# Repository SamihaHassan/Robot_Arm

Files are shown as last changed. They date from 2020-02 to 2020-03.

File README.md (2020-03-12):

# Robot_Arm
#### **``Purpose:``**

We aim to create a 2DOF parallel link robot arm that plays piano

#### **``Components:``**
* **Micro-controller:**  Arduino Mega 2560 board
* **Controller:** PID, made by [Samiha](https://github.com/SamihaHassan) and [Gaurika](https://github.com/GaurikaSohnvi)
* **Motor:** custom made reluctant motor by [John](https://github.com/JohnForssander) and Robert

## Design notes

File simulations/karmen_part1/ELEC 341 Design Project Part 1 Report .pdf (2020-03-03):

# Entire System Together

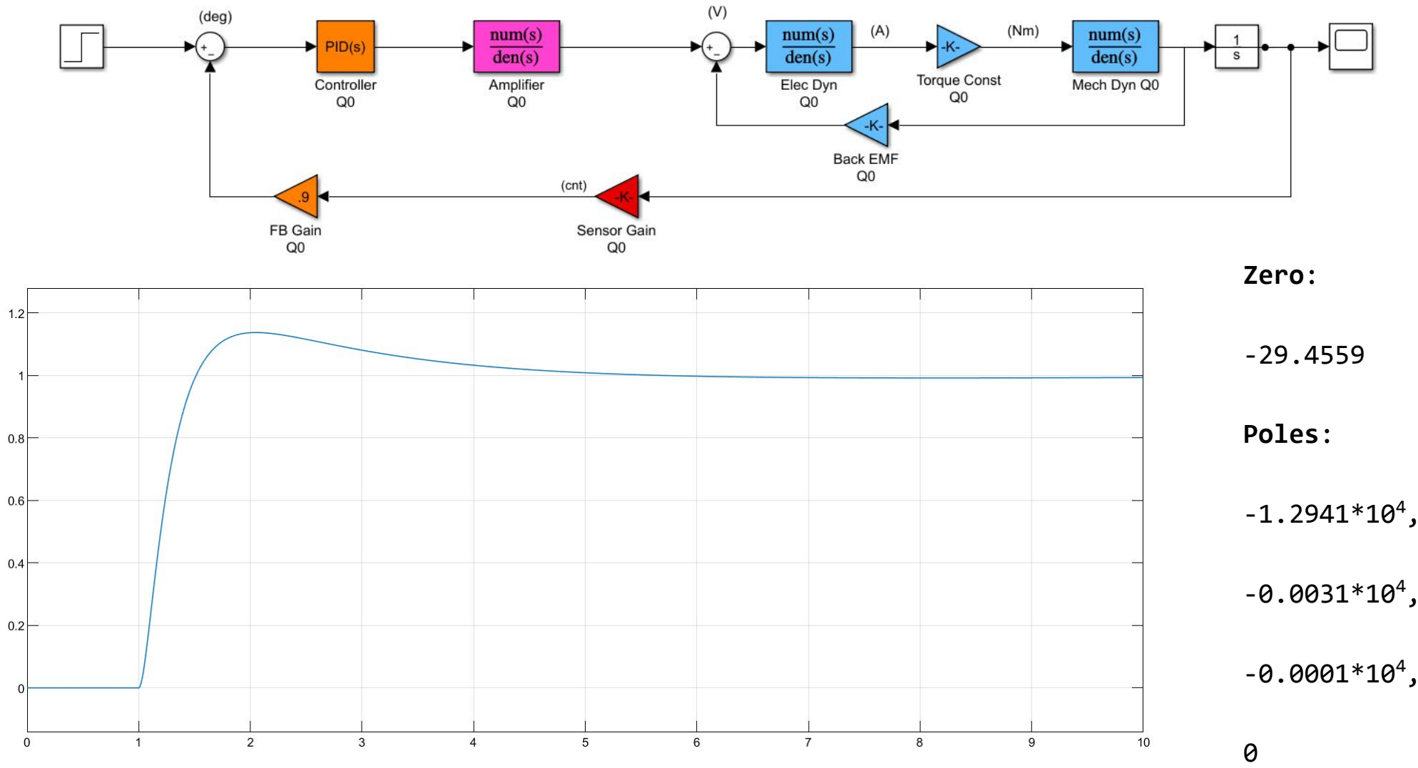
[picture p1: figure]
Zero:; Poles:

,

,

,

0 | 1

This is the overall schematic of our model. As seen, there is a PID(s) that gets multiplied by our linearized open loop response (the blue blocks), which outputs the angle (in radians) the 4 bar robotic arm will perform. To make the output in degrees a ‘radians to degrees’ block would be added after the integrator block. The feedback gain, is responsible for converting the analog signal from the sensor to an angular position measurement, as we are working with a linearized system, the FB gain will be 1/(sensor gain) to obtain unity gain.

We also used the top block diagram to test and generate the below step response that utilizes our PID gains computed (page 7). Using Matlab’s zero() and pole() functions we found the characteristics of the open-loop transfer function (provided above).

This report will detail the methods used to obtain the transfer functions of each component used in the system.

# Power Amplifier Circuit

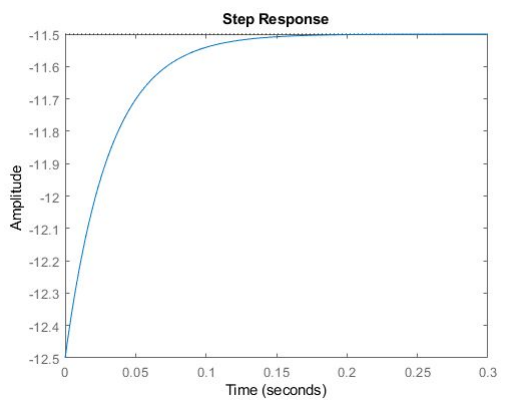
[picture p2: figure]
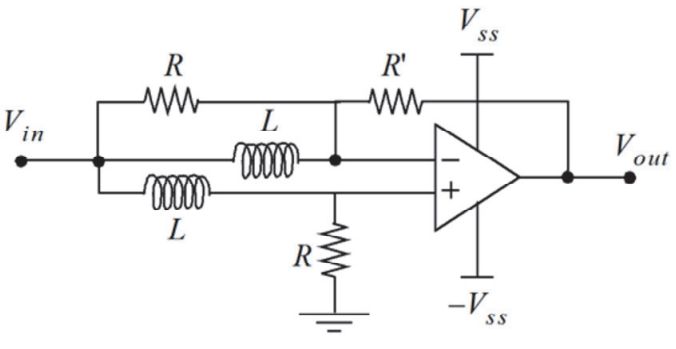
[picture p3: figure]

2

To compute the transfer function of the Power Amplifier circuit, we did the following:
- Transform the circuit into the Laplace domain, replace the components with their equivalent impedances (L becomes Ls for instance)
- Write out the following KCL equations and use MNA
- Also need to recognize that the amplifier has negative feedback therefore we can use the notion that V+ = V-
- Also recognize that there is no current being delivered to the non-inverting and inverting inputs to the OpAmp
Once this was done, we were able to determine the transfer function equation and simply replace the values with the ones provided in the datasheet. At a high level the transfer function makes sense as since there is negative feedback on the inverting input, the output signal should be flipped (the presence of the minus sign). However, this means that the input to the motor will be negative, so for the entire transfer function of the system we will multiply by -1.

# Electrical Motor Dynamics

3

+

Vin

+
ε

For the transfer function of the motor, being the Maxon ECX19M model, the electrical portion, i/Vin = 1/(Ls+R), was modeled using the simple circuit shown above using circuit analysis. The back emf and torque output was computed using the equations shown above.

The sensor gain was computed by taking the number of windows in an encoder (N = 100), by multiplying by 4 (4 readings), then dividing by 360 (degrees), we get the sensor gain of 1.111. We also linearized this system by setting the value of Floor = 1 which is equivalent to “removing” this block.

# Mechanical Dynamics - Inertia

4

The inertia of each component on the robot arm was found by setting the Bullgear as the Origin point and performing respective inertia calculations:

- UpperArm0 and ForeArm1 utilized the rod inertia equation
- UpperArm1 and ForeArm0 utilized the shifted rod inertia equation as it has a shift from the origin point
- The gripper utilized the point inertia equation with distance r from the origin
- Pinion inertia was calculated with the estimation of gear inertia provided in the document by Dr. Stocco

5

# Mechanical Dynamics - Linearization

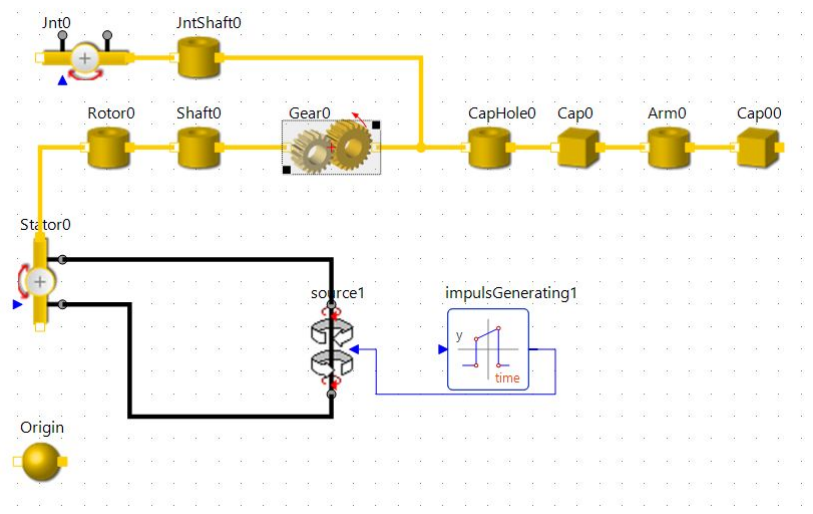
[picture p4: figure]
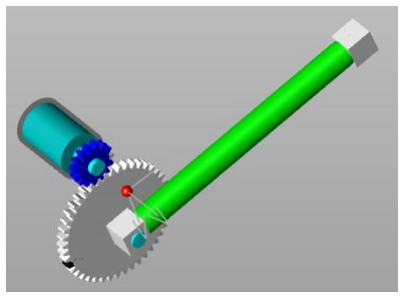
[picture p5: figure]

In order to obtain the B value, we had to first linearize the system. This meant blocks that were non-linear were “removed” from the simulation schematic as well as setting our flags in model.m to 0 to turn “off” different models of the system. To find the B in 1 gear, we deleted all of the system except for the gears, motor, UpperArm0 and other connecting elements that were needed. This simple system now experiences half of the total inertia we calculated (1.2176*10^(-4)/2), we then set our UpperArm0 mass and density to 0 so the end point of the rod (Cap00) experiences point inertia. We then calculated the equivalent mass of Cap00 in order to create the inertia needed for our revised system.

We added in an impulse generator block in order to see how our system behaves graphically as well as set our torque in “source 1” to the nominal torque of the motor in order to simplify the simulation. The linearization of the 4 Bar system will assist us in our B estimation between the gears.

# Mechanical Dynamics - B Estimation

6

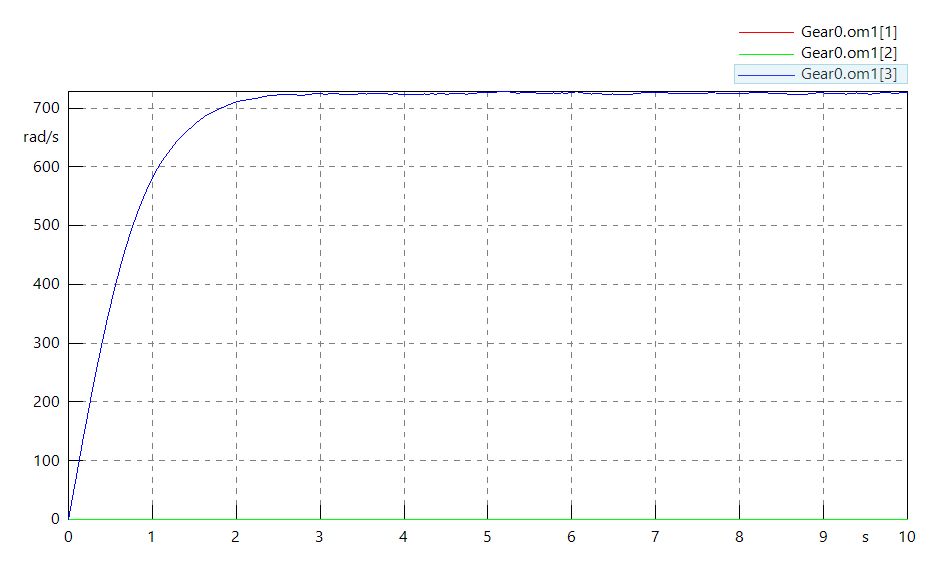
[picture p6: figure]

τ | ω

The angular velocity vs time graph models the performance of the pinion gear when simulated with the revised system shown in the previous slide. The steady state of the graph reached around 728.2 rad/s. The mechanical transfer function represents output/input which is angular frequency / torque constant (also known as nominal torque = 7.57E-3). Since our angular frequency (728.2 rad/s ) is taken at steady state, we must perform final value theorem on the transfer function.
By doing the final value theorem of the mechanical transfer function we obtain (728.2 1/s)/(7.47E-3 Nm) = 1/B, therefore the estimation of B = 1.0258E-5 kgm^2/s.

# PID Theoretical Design

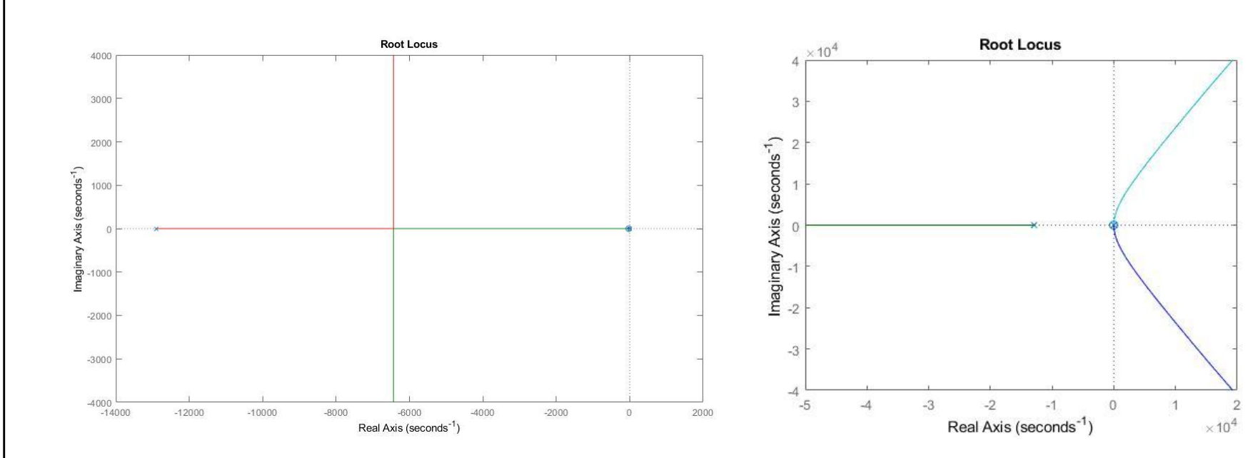
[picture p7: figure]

7

Since we have a modelled system, we do not need to use the guess-and-check methods, such as the Ziegler-Nichols method, to compute the initial PID gains. Instead we can use the Root Locus and the open loop transfer function to find the gains systematically.
- First we need to find the open loop transfer function of the entire system (as seen above)
- Then we can plot the Root Locus of the transfer function
- Next we picked two of the zeros included in the PID function to cancel out the two most unstable poles in the open loop transfer function (these being s = -31, and s = -1)
- From there we can equate them to the characteristic equation of the PID transfer function
- From this we get: Kp = Kd and Ki = 31/Kd
- Now we just need to find Kd - to do this we plotted the Root Locus of the KGH transfer function and picked an s value (being -6440 as it is most stable from the left Root Locus plot), and solved for Kd using the magnitude criteria |KGH| = 1
Along with this method, we also found that in Simulink, there is a PID controller tuning block. We used this to find optimized values for the P, I and D gains by setting requirements such as the rise time, damping, and having no steady state error. In the end we came up with the following gains:
Kp = 0.0672
Ki = 0.0120
Kd = 0.0918

# Part I (ELEC 341 Project) Done by:

### Mattias Zurković 75106880

### Karmen Wang 54144183

8

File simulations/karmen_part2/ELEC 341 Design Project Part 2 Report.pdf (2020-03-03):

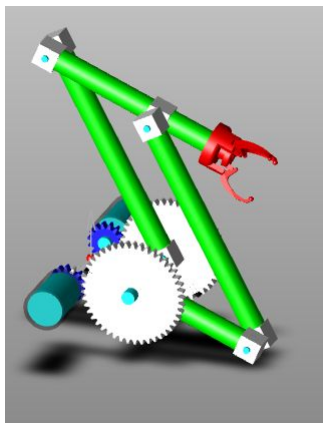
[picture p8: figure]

# System Overview

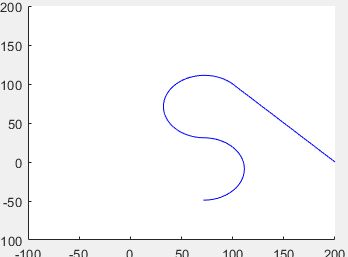
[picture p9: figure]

Input path of arm

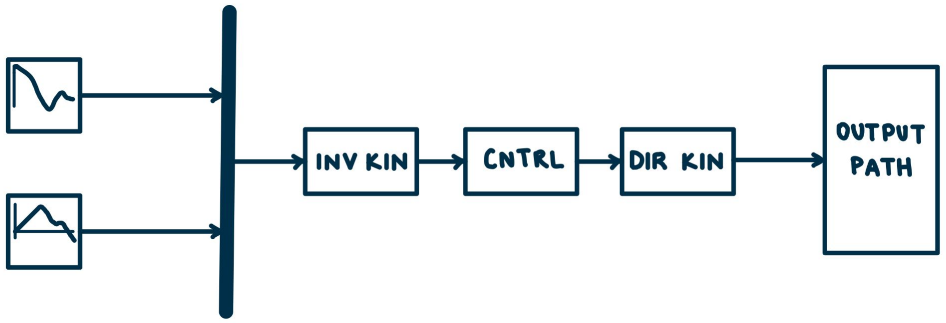
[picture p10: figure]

From the block diagram on the left, a vector of x and y coordinates are inputted to the system (the desired position of the end effector of the arm). The coordinates first get passed through an inverse kinematics block which changes the x and y parameters to joint space angles of the two motors (q0, q1) of the robot. The desired angles are then sent into the controller, which from part 1, computes how the robot needs to correct itself (with the use of a PID controller) due to the error from the actual position and desired angle position. Finally, the actual angles of the motors are sent to the direct kinematics block which is responsible for converting them back into the actual x and y coordinates of the end effector and plotted to see the path it takes.

# Direct Kinematics

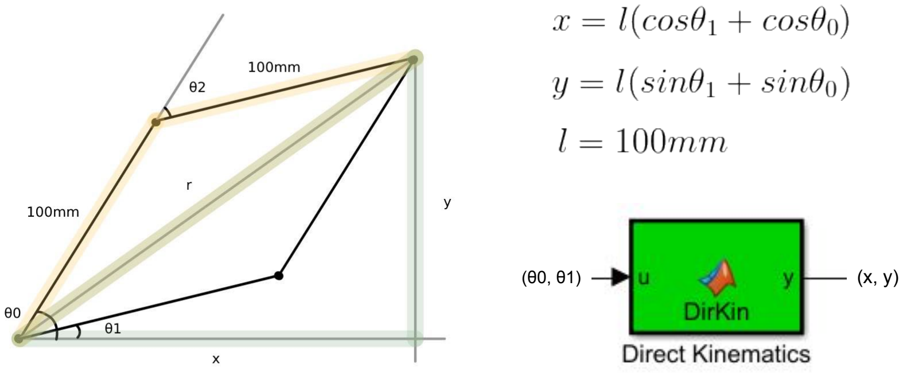
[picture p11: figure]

Direct kinematics outputs a position in the (x, y) coordinate for the End Effector from a given the motor angles: u0, u1 as its parameters.
Since there is a 1:3 gear ratio, we must scale our parameters (u0,u1) by -⅓ as we are going from angle of the motor/pinion to the bullgear. (θ0 = u0/-3, θ1 = u1/-3)

We calculated the x coordinate by obtaining the x components (l*cos(theta)) of each bar and adding them together and did the same for the y coordinate and used l*sin(theta), this is similar to vector addition between the arms to get our output end point/ position.

# Inverse Kinematics

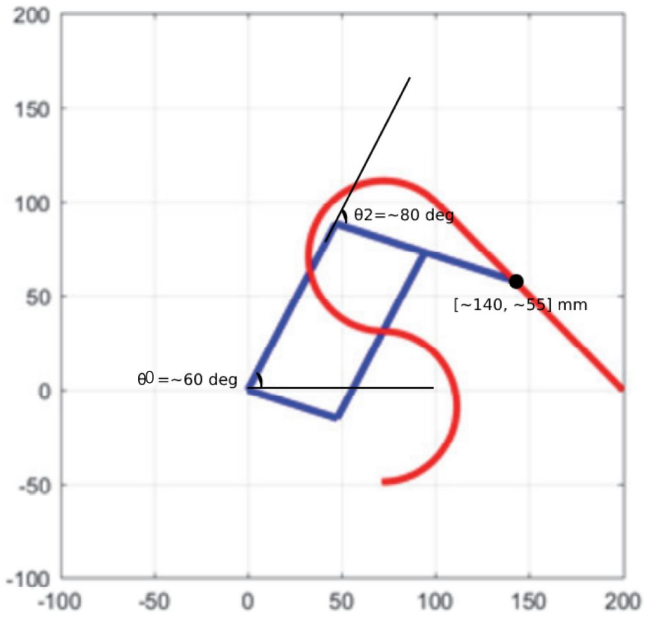
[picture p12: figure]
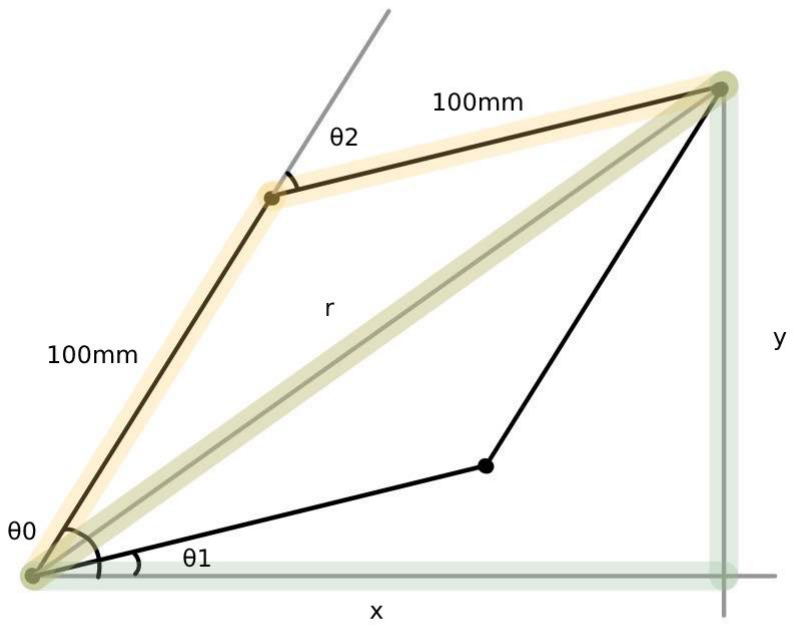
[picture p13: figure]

The purpose of the inverse kinematics block is to convert the desired (x, y) coordinates to the desired joint angles - it converts from cartesian coordinates to joint space angles for the robot.

To compute the joint angles θ0 and θ1, we approximated the four-bar linkage into two triangles (the highlighted yellow and green above) and saw that the yellow triangle can be assumed to be isosceles. From there we just used trigonometric identities and we derived the equations above. Due to the 1:3 gear ratio, we need to scale our outputs (θ0, θ1) by -3. The negative scaling is due to the direction of the gear turning with respect to the pinion.

We know our equations are correct because we inputted some test values (taken from the project description) and got that the outputs were 62.7 degrees and 82.5 degrees, which based on the picture is correct.

# PID Tuning

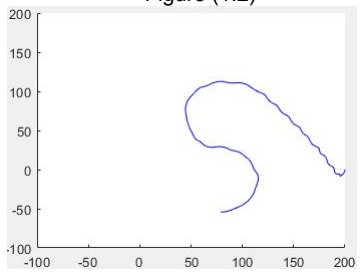
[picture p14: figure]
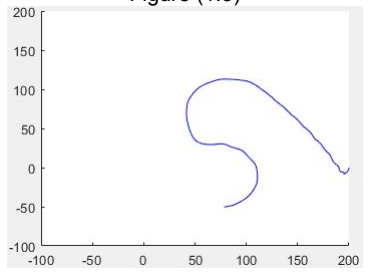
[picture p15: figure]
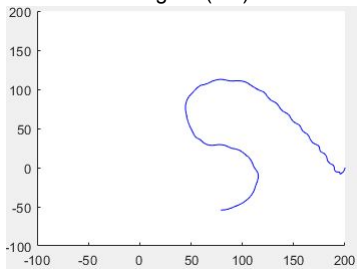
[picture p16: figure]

P: 0.085 I: 0.00065 D: 0.027 | P: 0.065 I: 0.00095 D: 0.0050 | P: 0.0502 I: 0.00115 D: 0.0105
Rise Time | Overshoot | Settle Time | Steady State Error
KP | ↓ | ↑ | ↑ | ↓
KI | ↓ | ↑ | ↑ | Eliminate
KD | ↑ | ↓ | ↓ | No effect
Figure (1.1) | Figure (1.2) | Figure (1.3)

Position - XY Plot

Regarding PID tuning, we started off with our initial values on the right. To get these first values we set the I and D gains to a relatively low number to effectively get rid of their influence on the response. From there the P gain was increased until the system slightly oscillated and the rest of the gains were determined by using intuition from understanding what each of them do, with the help of the above chart as high level reference.

However as it can be seen, the arm’s response was still not ideal so we fine tuned the rest. Due to the oscillations, we decreased the P gain (as can be seen in the centre image). This response also showed overshoot and a subtle amount of oscillations at the start of the path.

We reached our final PID gains by further decreasing the P and increasing the D to smooth out the curve. Along with this to get rid of the sharp turn in the middle of the path, when the arm changes direction, the I gain was increased as well. The reason why the arm dips at the start is due to gravity and the system starting, with all the tuning we did we could not fully get rid of the initial dip error.

# System Performance: Path Error Plot

Figure (2.1) | Figure (2.2) | Figure (2.3)

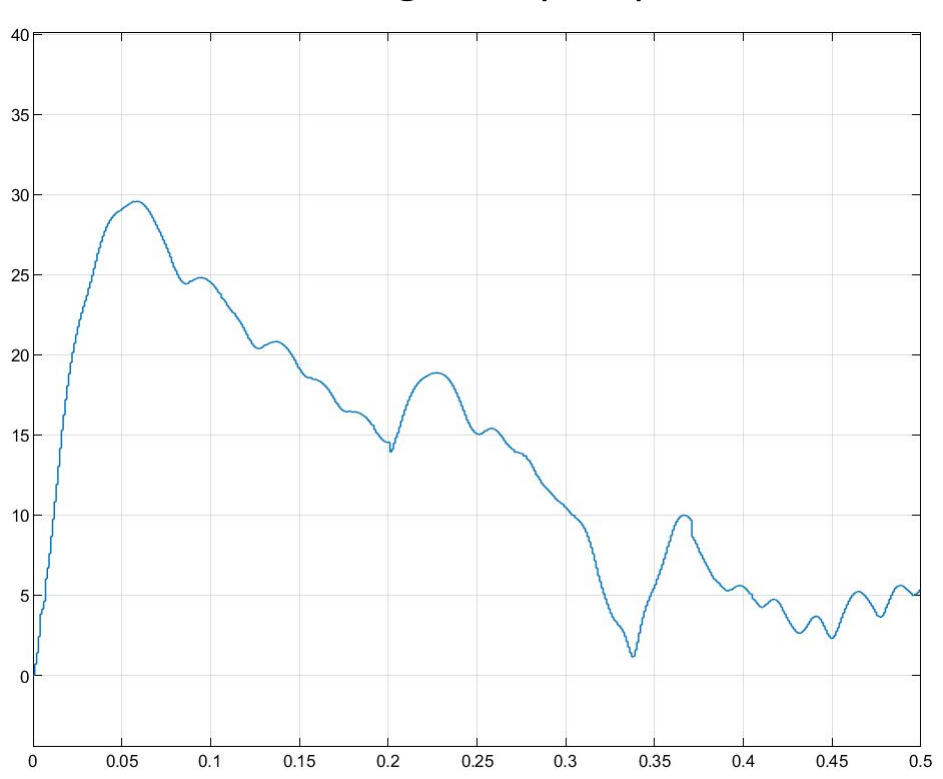
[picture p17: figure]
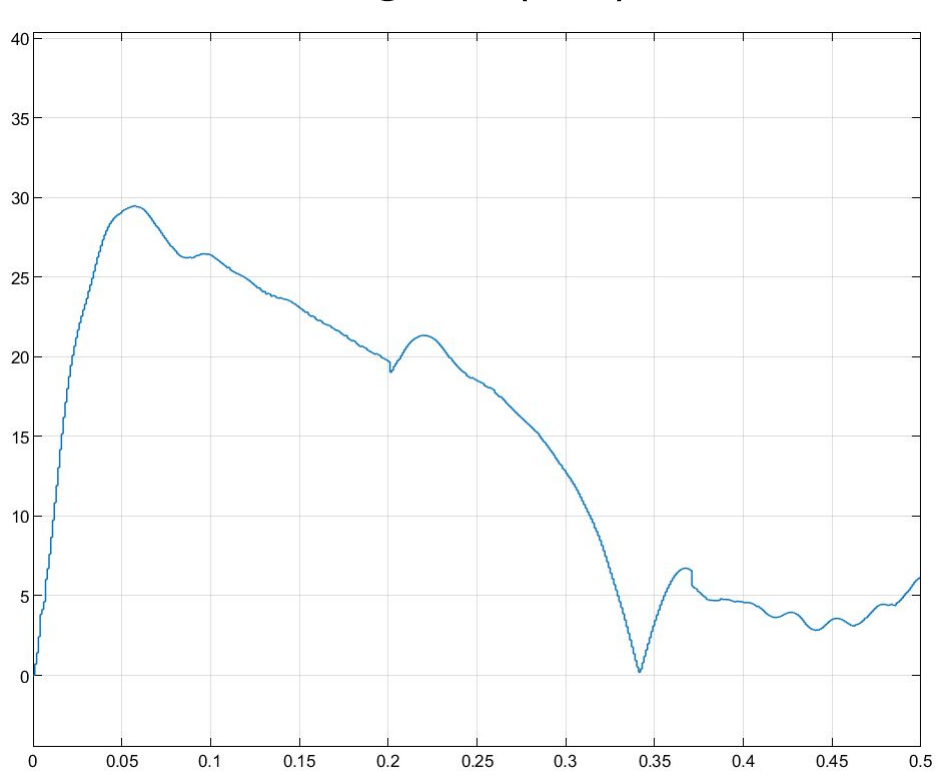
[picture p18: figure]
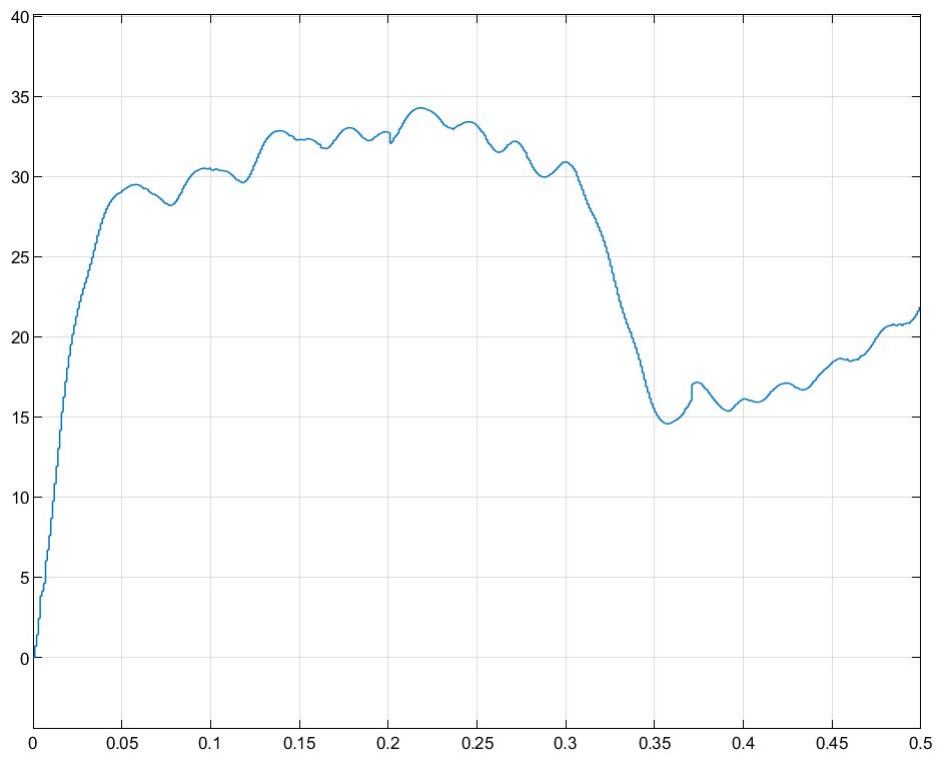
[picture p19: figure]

P: 0.085 I: 0.00065 D: 0.027 | P: 0.065 I: 0.00095 D: 0.0190 | P: 0.0502 I: 0.00115 D: 0.0105

Here are the following images of the path error correlating with PID tuning position plots in the previous slide. The goal of the path error plot is to minimize our path error, this can also be seen by having our error (y axis) be as close to 0 as possible. All 3 figures have large initial error due to the initial dip from gravity.

As seen, our first sample of PID tuning (figure 2.1), we had a fairly poor path error plot. The error average of the plot was very high, therefore, the the PID’s chosen for this sample is not ideal.

In our second sample of PID tuning (figure 2.2), the chosen PID’s allowed our path error avg to be significantly smaller than our previous sample. Comparing to our position plots from our previous slide, there was a lot of “shakiness” in the plot, this translated to a shaky path error plot, meaning we could improve on the P and D tuning to account for “shakiness” (more detailed explanation on page 3).

Our final chosen PID gains (figure 2.3) shows a steadily decreasing path error plot with some increase in error at the end due to the sharp turn. The max error of system was 29.43 mm.

# System Performance: Step Response

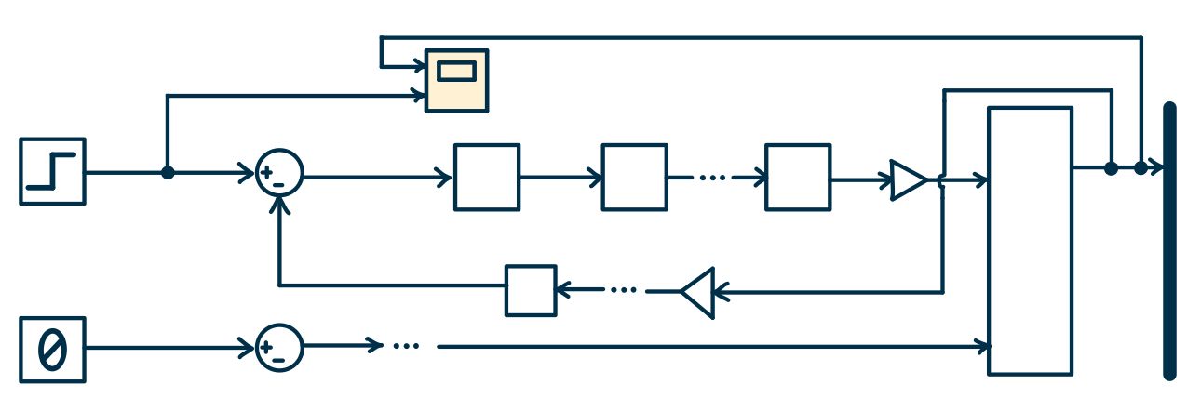
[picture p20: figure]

Modified system to determine step response

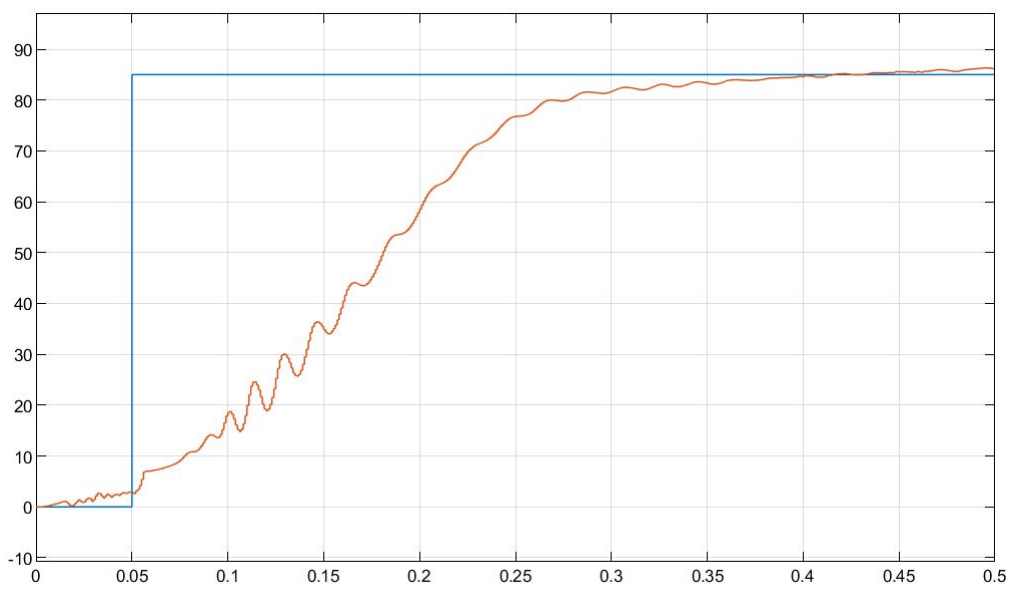
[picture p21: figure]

Step response

To evaluate the joint space system, the system model was modified. We took out the input MUX and added a step input to one of the motors (q0 in this case) and set an input of 0 to the other motor so it would not interfere. We connected the input step and the output (after the SimulationX coupling) to a scope and the step response on the right was achieved. The input angle was set to 85 degrees as this is a reasonable angle that the motor had to achieved based on the given description (as seen on page 3).

From analyzing this step response we see that the joint space portion of the system has a rise time of roughly 0.215s and has negligible steady state error due to correctly tuning the I gain in the controller. We could decrease the rise time by increasing the P gain however then the system would overshoot and be less stable as it settles to steady state.

# Project By:

### - Mattias Zurković 75106880 - Karmen Wang 54144183

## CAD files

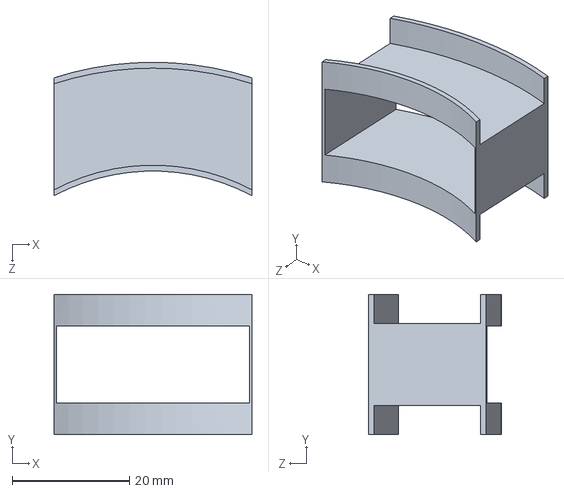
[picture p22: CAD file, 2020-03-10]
solidworks/Motor Parts/Winding Wrapper 2.22.SLDPRT
33.7 x 23.9 x 22.7 mm

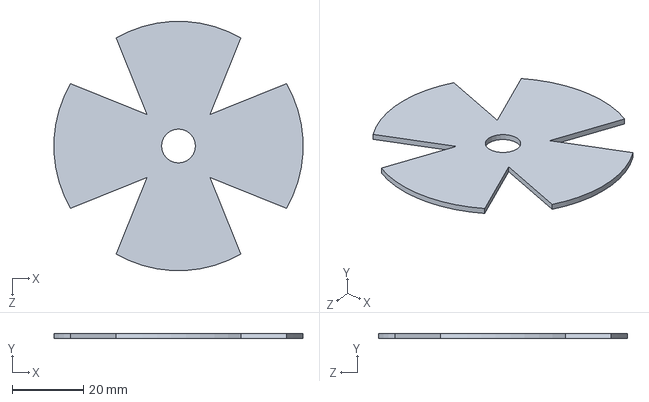
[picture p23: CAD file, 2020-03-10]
solidworks/Motor Parts/Rotor Lamination.SLDPRT
69.9 x 1.52 x 69.9 mm

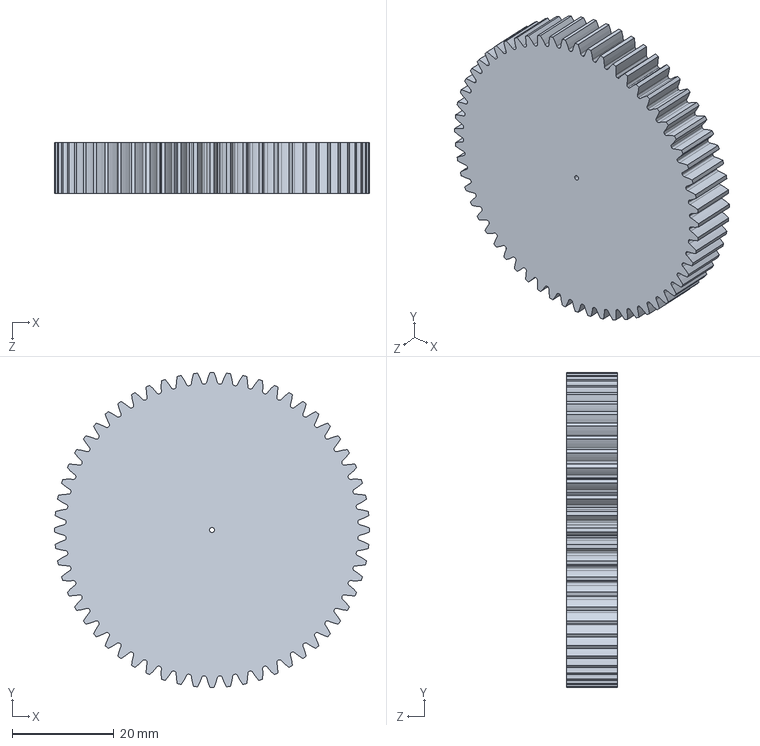
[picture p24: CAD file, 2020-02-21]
solidworks/Control Team/Pinion60.SLDPRT
62.0 x 62.0 x 10.0 mm

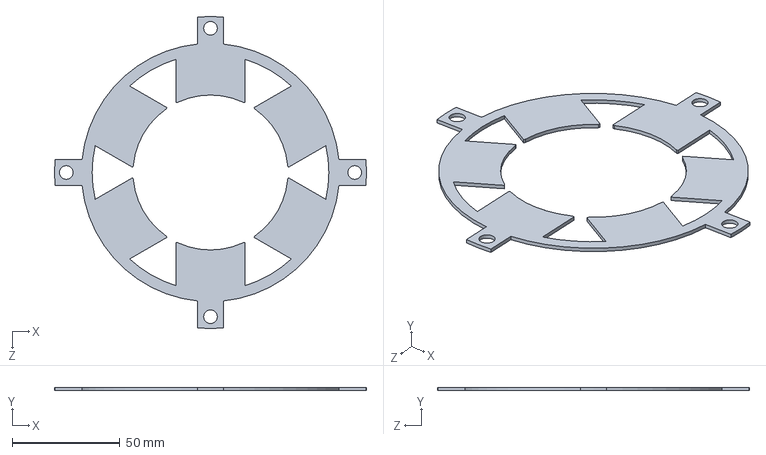
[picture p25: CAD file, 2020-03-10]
solidworks/Motor Parts/Stator Lamination.SLDPRT
145.0 x 1.52 x 145.0 mm

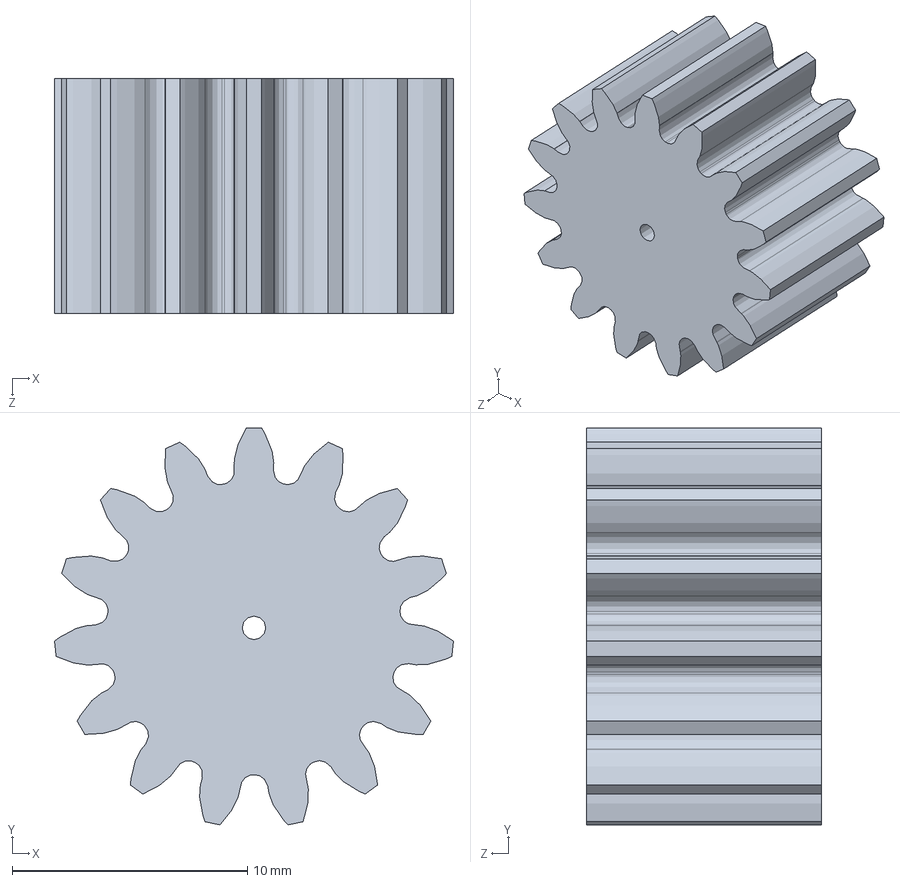
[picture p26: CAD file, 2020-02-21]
solidworks/Control Team/Pinion15.SLDPRT
17.0 x 16.9 x 10.0 mm

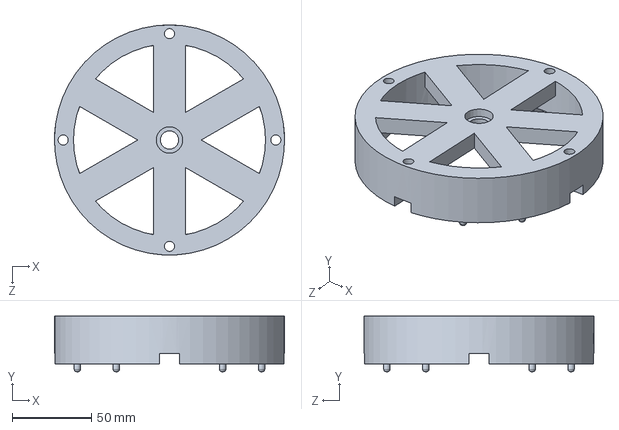
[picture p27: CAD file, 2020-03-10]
solidworks/Motor Parts/Motor Housing Male 1.11.SLDPRT
144.9 x 35.0 x 145.0 mm

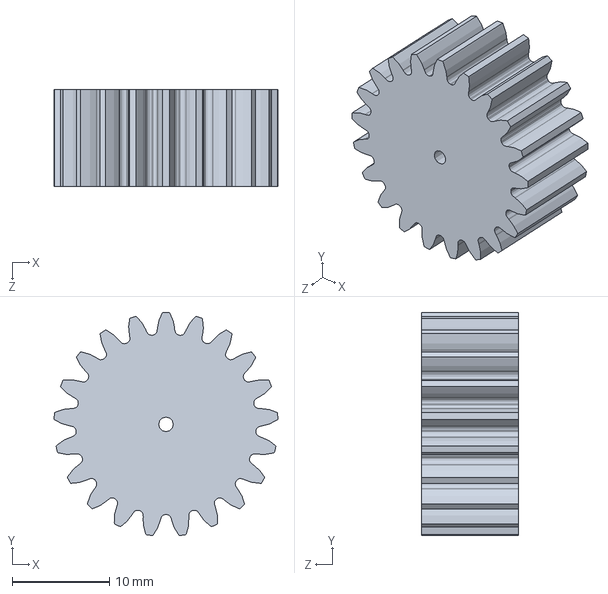
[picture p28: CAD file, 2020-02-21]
solidworks/Control Team/Pinion15_stocco.SLDPRT
23.0 x 22.9 x 10.0 mm

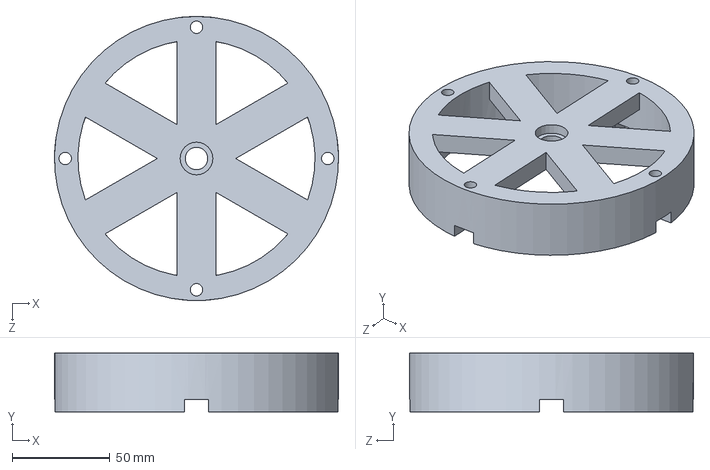
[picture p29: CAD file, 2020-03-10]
solidworks/Motor Parts/Motor Housing Female 1.11.SLDPRT
144.9 x 30.0 x 145.0 mm

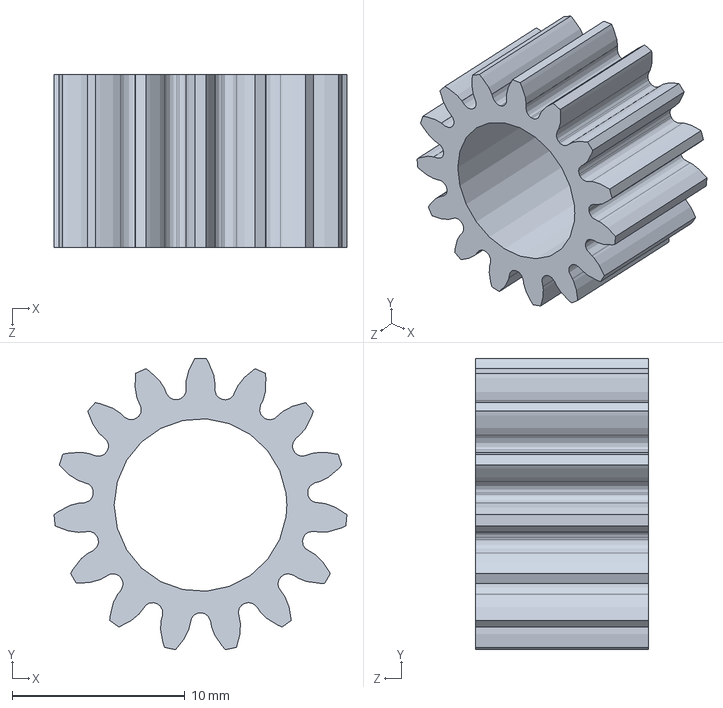
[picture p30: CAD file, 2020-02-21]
solidworks/Control Team/Pinion15_original.SLDPRT
17.0 x 16.9 x 10.0 mm

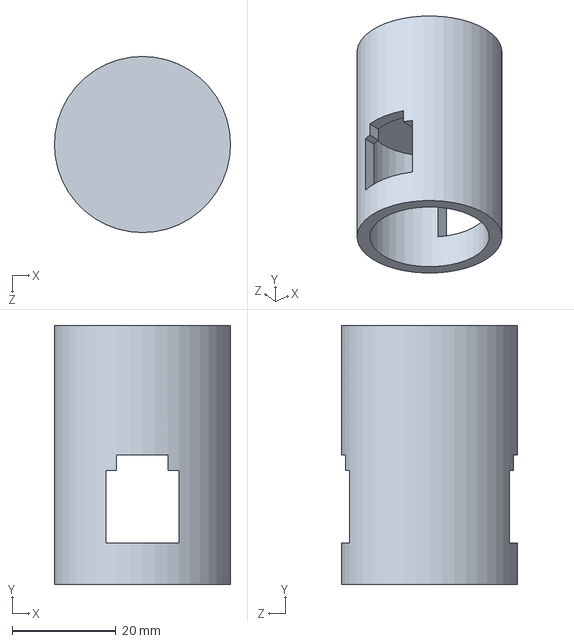
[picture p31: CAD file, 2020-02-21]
solidworks/Control Team/dcmotor_case.SLDPRT
34.0 x 50.0 x 34.0 mm

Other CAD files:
solidworks/Control Team/Pinion15.STL
solidworks/Control Team/Pinion60.STL
solidworks/Control Team/dcmotor_case.STL

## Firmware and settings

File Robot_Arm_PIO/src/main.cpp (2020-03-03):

#include <stdlib.h>
#include <Arduino.h>
#include <globals.h>
#include <pid_controller.h>
//#include <Ticker.h>

int valA = 0;
int valB = 0;
int dir = 0;
int count = 0;
float thetaDeg = 0;
float thetaDesired = 0;
float thetaDiff = 0;
int pid = 0;
int pwm = 0;

//PID controller variables 
unsigned long time = 0; 
unsigned long prev_time = 0; 
unsigned long delta_t; 
float error; 

void secondsDelay(int n);

//Interrupts from slot detectors to determine the direction of spin
void ISRA();
void ISRB();
//motor driver setup
void setFWD();
void setREV();
//compute PID function in pid_controller lib and apply PID in main
void applyPID();

PID* PIDA = new PID();

void setup() {
  Serial.begin(9600);
  attachInterrupt(digitalPinToInterrupt(RUPT_PIN_A),ISRA,CHANGE);
  attachInterrupt(digitalPinToInterrupt(RUPT_PIN_B),ISRB,CHANGE);
  valA = digitalRead(RUPT_PIN_A); //initial reading
  valB = digitalRead(RUPT_PIN_B);
  dir = (valA ^ valB) ? 0 : 1;
  count = 0;
  pinMode(MOTOR_PIN_A, OUTPUT); //PWM pin
  pinMode(DIREC_A, OUTPUT); 
  pinMode(DIREC_B, OUTPUT); 
  setREV();
  analogWrite(MOTOR_PIN_A, 0); 
  secondsDelay(3);
  analogWrite(MOTOR_PIN_A, 100); 
} //end setup

void loop()
{        
    //Serial.println(dir);
    Serial.println("---------------------------------");
    //read input for theta setpoint; thetaDesired = ?
    thetaDesired = 120;
    Serial.print("thetaDesired: ");
    Serial.println(thetaDesired);
    //read theta from encoder;
    thetaDeg = DEG((float)count*1.8); //Serial.println(thetaDeg); //thetaDeg = 45;   
    Serial.print("thetaActual: ");
    Serial.println(thetaDeg);
    //inputs for PID
    
    error = thetaDesired - thetaDeg; 
    //thetaDiff = DEG(thetaDesired - thetaDeg); 
    Serial.print("error: ");
    Serial.println(error);
    Serial.print("thetaDiff: ");
    Serial.println(thetaDiff);

    prev_time = time; 
    time = millis(); 
    delta_t = time - prev_time; 

    //compute PID on theta desired
    pid = (PIDA->ComputePID(delta_t, error));
    Serial.print("PID pwm: ");
    Serial.println(pid); 
    
    analogWrite(MOTOR_PIN_A, abs(pid));
    if (pid < -5) {
      setFWD();
    }
    else if (pid > 5) {
      setREV();
    }
    // else if ((pid>-50)&&(pid<50)) {

    // }
    else
    {
      analogWrite(MOTOR_PIN_A, 0);
    }
    delayMicroseconds(50);
    
    //use PID signal to follow trajectory 
    //applyPID();
  
    
} //end main


void ISRA() {
  dir = (valA ^ valB) ? 0 : 1;
  valA = digitalRead(RUPT_PIN_A);
  dir ? count++ : count--;
  
}

void ISRB() {
  valB = digitalRead(RUPT_PIN_B);
  dir = (valA ^ valB) ? 0 : 1;

}


void setREV() {
  Serial.println("REV");
  digitalWrite(DIREC_A, LOW);
  digitalWrite(DIREC_B, HIGH);
}

void setFWD() {
  Serial.println("FWD");
  digitalWrite(DIREC_A, HIGH);
  digitalWrite(DIREC_B, LOW);  
}

void secondsDelay(int n) 
{
    int i = 0;
    for (i=0; i < n; i++) {
      delay(1000);
    }  
}

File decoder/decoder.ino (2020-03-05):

#define MAX_NUM 40
int ruptPinA = 2;
int ruptPinB = 3;
int valA = 0;
int valB = 0;
int dir = 0;
int count = 0;
float last_theta = 0;
float now_theta = 0;
unsigned long last_time = 0;
unsigned long now_time = 0;
float AngSpeed = 0;
float arr[200][2];

int motorPin = 4;
int DirecOne = 7;
int DirecTwo = 6;

//MATLAB readings for graph 
#define timePin 8
#define speedPin 9

//time delay 
void secondsDelay(int n);

//Interrupts from slot detectors to determine the direction of spin
void ISRA();
void ISRB();

//motor driver setup
void spinFWD();
void spinREV();



void setup() {
  Serial.begin(115200);
  attachInterrupt(digitalPinToInterrupt(ruptPinA),ISRA,CHANGE);
  attachInterrupt(digitalPinToInterrupt(ruptPinB),ISRB,CHANGE);
  valA = digitalRead(ruptPinA); //initial reading
  valB = digitalRead(ruptPinB);
  dir = (valA ^ valB) ? 0 : 1;
  count = 0;

  //Motor PIn definition 
  pinMode(motorPin, OUTPUT); //PWM pin
  pinMode(DirecOne, OUTPUT); 
  pinMode(DirecTwo, OUTPUT); 

  //Matlab Pin Definition 
  pinMode(timePin, OUTPUT); 
  pinMode(speedPin, OUTPUT); 
  
  spinFWD();
  Serial.print("done setup\n");
  secondsDelay(3);
  Serial.print("start loop\n");
  
}

void loop()

{   
    static int a = 0;
  
    last_time = now_time;
    last_theta = now_theta;
    int speed = 70; //motor pwm - keep it slow
    
    analogWrite(motorPin, speed); 
    secondsDelay(1);
    
    now_theta = (float)count*1.8;
    now_time = millis();
    
    arr[a][1] = now_time;
    AngSpeed = (now_theta-last_theta)/(float)(now_time-last_time);
    arr[a][0] = AngSpeed;
//    Serial.print("now_theta\t");
//    Serial.print(now_theta);
//    Serial.print("\n\tspeed\t");
//    Serial.print(AngSpeed);
//    Serial.print("\ttime\t");
//    Serial.println(now_time);
  
  a++;
  if (a>MAX_NUM) {
     for (int i=0; i<MAX_NUM; i++) {
      for (int j=0; j<2; j++) {
        Serial.print(arr[i][j]);
        Serial.print("\t");
      }
       Serial.print("\n"); 
     } 
    Serial.print("done code\n");
  }
  
}


void ISRA() {
  dir = (valA ^ valB) ? 0 : 1;
  valA = digitalRead(ruptPinA);
  dir ? count++ : count--;
  
}

void ISRB() {
  valB = digitalRead(ruptPinB);
  dir = (valA ^ valB) ? 0 : 1;

}


void spinFWD() {
  digitalWrite(DirecOne, LOW);
  digitalWrite(DirecTwo, HIGH);
}

void spinREV() {
  digitalWrite(DirecOne, HIGH);
  digitalWrite(DirecTwo, LOW);  
}

void secondsDelay(int n) 
{
    int i = 0;
    for (i=0; i < n; i++) {
      delay(1000);
    }  
}

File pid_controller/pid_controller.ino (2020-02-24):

#include <stdlib.h>
#include <Arduino.h>
#include "pid_controller.h"

unsigned long delta_t = 0;

float PID(PIDVariables* motorPID, float theta_desired) {

    motorPID->time = millis();
    delta_t = motorPID->last_time - motorPID->time;
    //theta_current = ReadTheta(0); //0 represents first motor
    motorPID->error = theta_desired - motorPID->theta;
    motorPID->proportional = motorPID->error * K_P;
    motorPID->derivative = (motorPID->error - motorPID->prev_error) * K_D;
    motorPID->errorSum += motorPID->error;
    motorPID->integral += motorPID->errorSum * delta_t * K_I;
    
    motorPID->prev_error = motorPID->error;
    motorPID->last_time = motorPID->time;
    
    return motorPID->proportional + motorPID->derivative + motorPID->integral;

} //end

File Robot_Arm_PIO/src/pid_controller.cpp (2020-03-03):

#include <stdlib.h>
#include <Arduino.h>
#include <pid_controller.h>

PID::PID() {
    this->proportional = 0.0; 
    this->derivative = 0.0;
    this->integral = 0.0;
    this->errorSum = 0.0;
    this->prev_error = 0.0;
}

int PID::ComputePID(unsigned long delta_t, float error) {
    Serial.print("prev_error: ");
    Serial.println(this->prev_error);
    // Serial.println("entered Compute PID");

    // theta_current = ReadTheta(0); //0 represents first motor

    proportional = error * K_P; 
    if (delta_t > 0) //so derivative term is not infinity
    derivative = (error - prev_error)/delta_t * K_D;
    
    
    // errorSum += error * (float)delta_t;
    // integral = errorSum * K_I; 
    Serial.print("proportional: ");
    Serial.print(this->proportional);
    Serial.print("  derivative: ");
    Serial.println(this->derivative);
    // Serial.print("  integral: ");
    // Serial.println(this->integral);
       
    prev_error = error;

    output = this->proportional + this->derivative + this->integral;
    Serial.print("PID output: ");
    Serial.println(output); 
    output = map((int)output, -180, 180, -255, 255);
    return output;
    
}; //end

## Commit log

2020-02-21 decoder file has dc motor with encoder, next step is to add pid and step down motor
2020-02-21 dc motor mount solidworks
    [dcmotor_case.SLDPRT, dcmotor_case.STL]
2020-02-21 1:4 gears STL files
    [Pinion15.SLDPRT, Pinion15.STL, Pinion15_original - Copy - Copy.SLDPRT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]
2020-02-24 rewrote PID since BSOD, still need to integrate to main
2020-02-24 calling it a night, need to fix pid_controller class and integrate
    [main.cpp, pid_controller.cpp]
2020-02-24 PID class code done, pending testing
2020-02-25 wip PID::ApplyPID()
2020-02-25 need to fix applyPID
    [pid_controller.cpp]
2020-02-26 finished pid in code, modified dcmotor testing code
2020-02-26 PID not outputting anything
2020-02-26 nan for pid terms
2020-02-27 initialization inside PID class now working
2020-02-27 PD controller, need to test with encoder
2020-02-28 algorithm fixed for the setpoint vs actual value
    [main.cpp, pid_controller.cpp]
2020-02-28 added PID, doesn't go to setpoint anymore
    [main.cpp]
2020-02-28 update: tried PD controller with abs error - does NOT work :(
    [main.cpp]
2020-03-02 encoder broken
2020-03-02 pid works
2020-03-03 pid works, only tuning will change now
2020-03-04 working on tf for motor and driver
2020-03-04 excel tf
    [excel_stuff.xlsx]
2020-03-05 same setup working on black 3D printed jig
2020-03-10 added motor stuff
    [Motor Housing Female 1.11.SLDPRT, Motor Housing Male 1.11.SLDPRT, Pinion15.SLDPRT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]
2020-03-13 Motor pcb schematics
    [Sheet1.SchDoc]
